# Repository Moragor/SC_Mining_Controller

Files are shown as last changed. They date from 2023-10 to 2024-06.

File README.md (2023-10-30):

# Star Citizen Mining Controller
A handheld mining controller for Star Citizen

Parts:
Arduino Pro Micro: https://www.aliexpress.com/item/32768308647.html

Switches: ON-ON 3-Pin https://www.aliexpress.com/item/4000598302546.html

Power Button: 19mm https://www.aliexpress.com/item/1005003151279874.html?gatewayAdapt=glo2deu

E-Stop: 19mm 3-Pin https://www.aliexpress.com/item/1005003736504591.html?gatewayAdapt=glo2deu

Module Buttons: https://www.aliexpress.com/item/32667944879.html?gatewayAdapt=glo2deu

Slide Potentiometer: ALPS 401547 (RS60112-LIN10K) + ALPS 76561 (KNOPF 4X1,2RT)

Joystick: APEM 3150RAK600

Switch rubber grommets: APEM U598

Front Panel: Order from https://www.schaeffer-ag.de/ (EU) or https://www.frontpanelexpress.com/ (NA)

Demo: https://www.youtube.com/watch?v=b_x-qhPem98

[][cc-by-nc-sa]

[cc-by-nc-sa]: http://creativecommons.org/licenses/by-nc-sa/4.0/
[cc-by-nc-sa-shield]: https://img.shields.io/badge/License-CC%20BY--NC--SA%204.0-lightgrey.svg

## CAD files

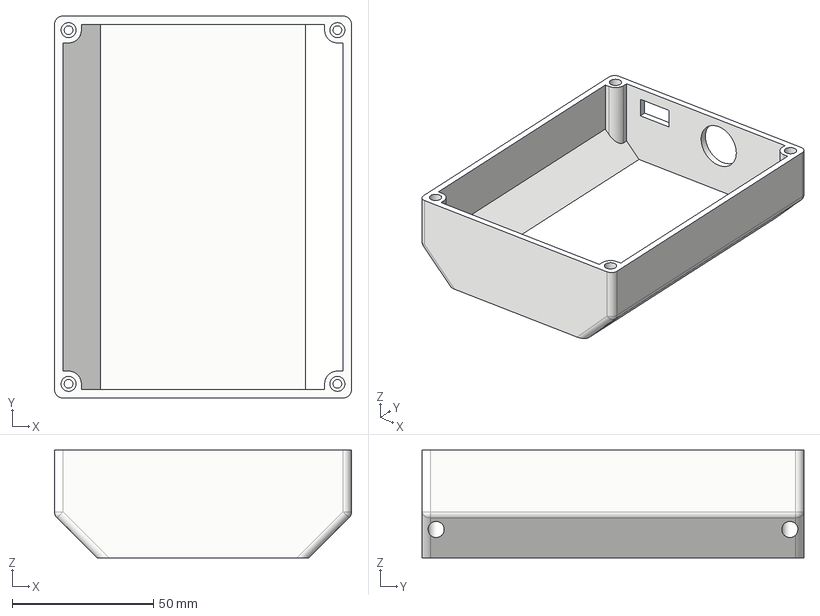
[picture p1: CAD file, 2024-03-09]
3D_Files/Mining Controller Case MKI v16.step
105.0 x 135.0 x 38.0 mm

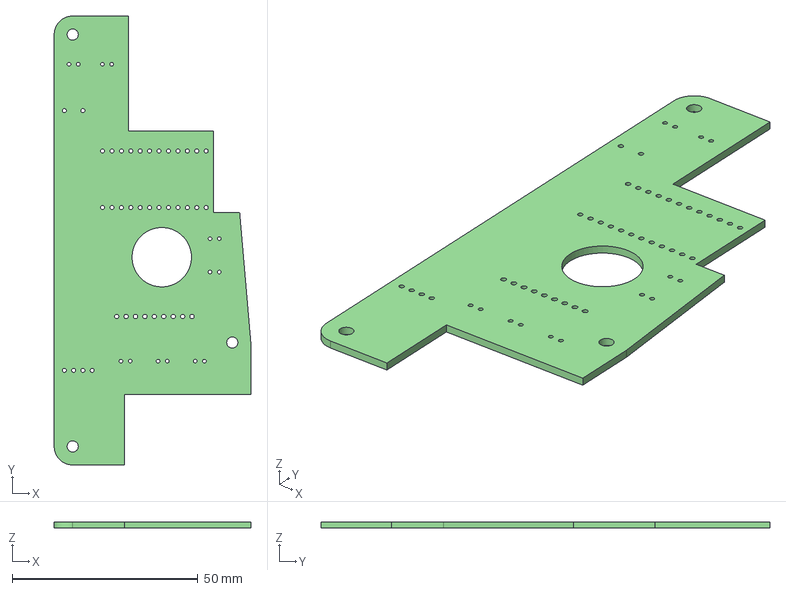
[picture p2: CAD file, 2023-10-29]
KiCad_Files/SC_Mining_Controller_MkI/SC_Mining_Controller_MkI.step
53.0 x 121.0 x 1.60 mm

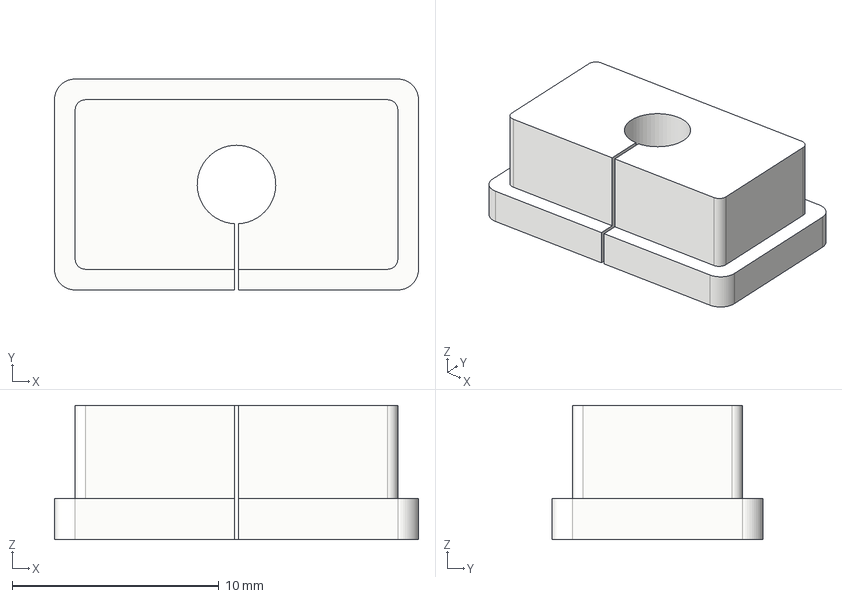
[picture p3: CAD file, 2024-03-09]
3D_Files/Minig Controller Strain Relief v2.step
17.6 x 10.2 x 6.50 mm

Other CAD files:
3D_Files/Case_MKI.stl
3D_Files/Strain_relief.stl

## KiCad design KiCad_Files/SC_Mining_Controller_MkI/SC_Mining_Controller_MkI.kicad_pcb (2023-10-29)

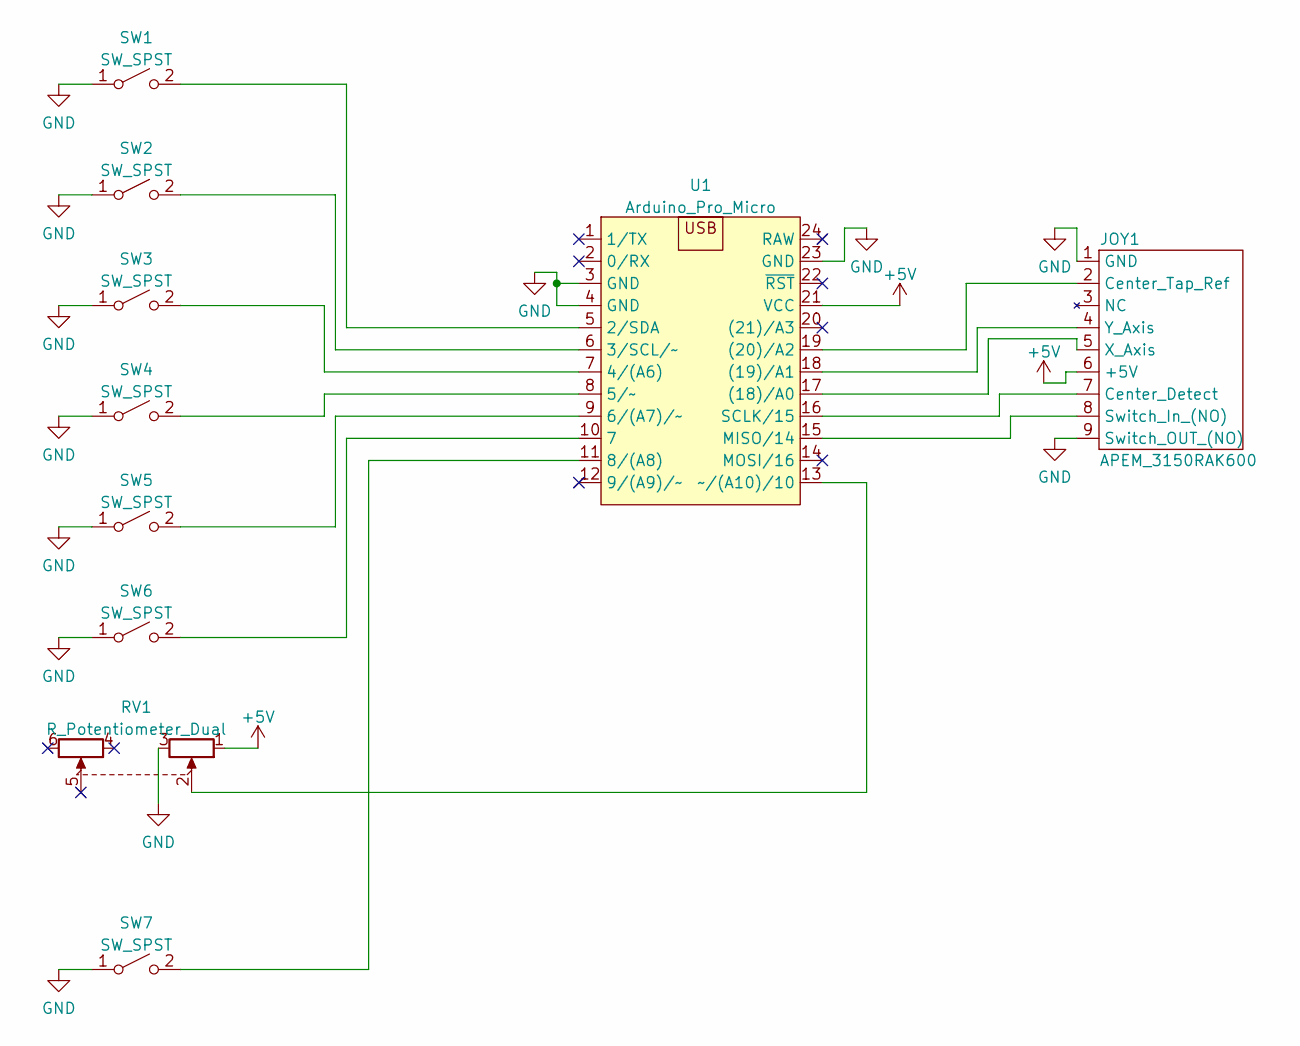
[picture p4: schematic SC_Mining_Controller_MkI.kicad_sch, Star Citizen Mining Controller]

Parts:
JOY1: APEM_3150RAK600; Molex_KK-254_AE-6410-09A_1x09_P2.54mm_Vertical
RV1: R_Potentiometer_Dual; Sliding_Potentiometer_RS60112
SW1, SW2, SW3, SW4, SW5, SW6, SW7: SW_SPST; JST_XH_B2B-XH-A_1x02_P2.50mm_Vertical
U1: Arduino_Pro_Micro; ProMicro

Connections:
+5V: JOY1.6 (+5V), RV1.1, U1.21 (VCC)
GND: JOY1.1 (GND), JOY1.9 (Switch_OUT_(NO)), RV1.3, SW1.1 (A), SW2.1 (A), SW3.1 (A), SW4.1 (A), SW5.1 (A), SW6.1 (A), SW7.1 (A), U1.3 (GND), U1.4 (GND), U1.23 (GND)
unnamed: JOY1.2 (Center_Tap_Ref), U1.19 ((20)/A2)
unnamed: JOY1.4 (Y_Axis), U1.18 ((19)/A1)
unnamed: JOY1.5 (X_Axis), U1.17 ((18)/A0)
unnamed: JOY1.7 (Center_Detect), U1.16 (SCLK/15)
unnamed: JOY1.8 (Switch_In_(NO)), U1.15 (MISO/14)
unnamed: RV1.2, U1.13 (~/(A10)/10)
unnamed: SW1.2 (B), U1.5 (2/SDA)
unnamed: SW2.2 (B), U1.6 (3/SCL/~)
unnamed: SW3.2 (B), U1.7 (4/(A6))
unnamed: SW4.2 (B), U1.8 (5/~)
unnamed: SW5.2 (B), U1.9 (6/(A7)/~)
unnamed: SW6.2 (B), U1.10 (7)
unnamed: SW7.2 (B), U1.11 (8/(A8))

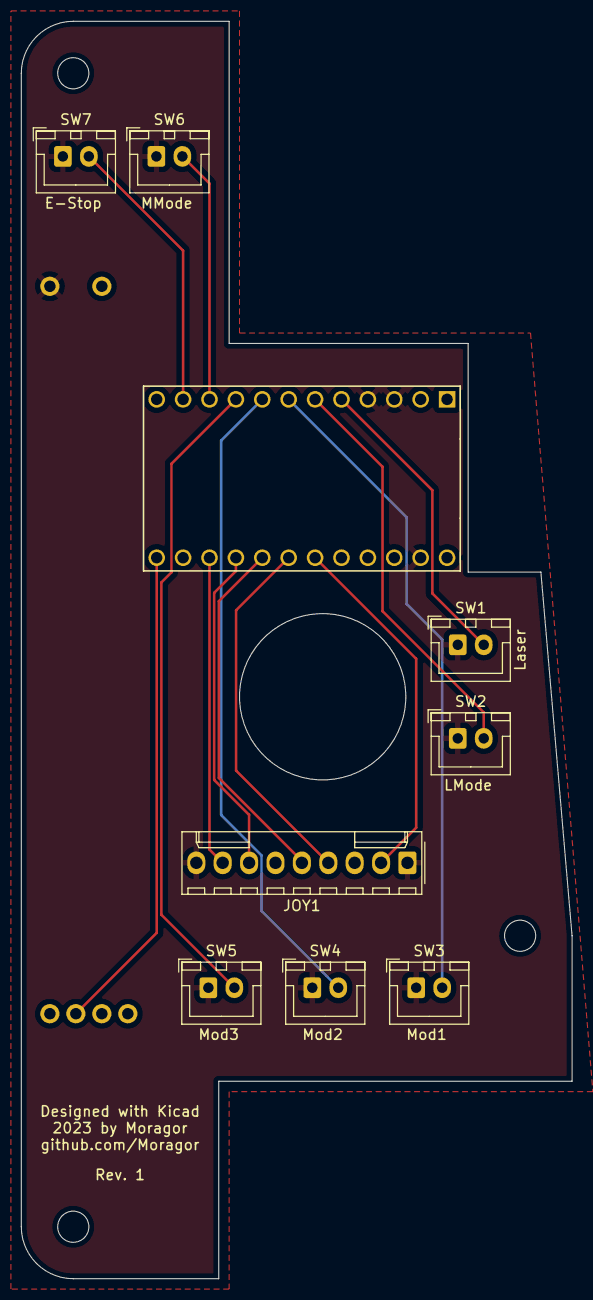
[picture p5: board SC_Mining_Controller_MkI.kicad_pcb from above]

Board: 2 copper layers, 53.0 x 121.0 mm, 10 parts (1 on the bottom side), 15 nets.

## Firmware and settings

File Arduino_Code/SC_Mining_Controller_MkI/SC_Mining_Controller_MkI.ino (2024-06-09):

#include <Bounce2.h>
#include <Joystick.h>     //https://github.com/MHeironimus/ArduinoJoystickLibrary

#define laserPin 2       //0 (array position)
#define lModePin 3       //1
#define mod1Pin 4        //2
#define mod2Pin 5        //3
#define mod3Pin 6        //4
#define mModePin 7       //5
#define eStopPin 8       //6
#define joyButtonPin 14  //7
#define xAxisPin A0
#define yAxisPin A1
#define centerTapPin A2
#define sliderPin A10

byte buttonDelay = 25;
const int numButtons = 8;                                                                                                // Number of buttons
const int buttonPins[numButtons] = { laserPin, lModePin, mod1Pin, mod2Pin, mod3Pin, mModePin, eStopPin, joyButtonPin };  // Pin numbers for your buttons

Bounce debouncer[numButtons];  // Create a debouncer object for each button

//Setting up the features of the joystick
Joystick_ Joystick(JOYSTICK_DEFAULT_REPORT_ID, JOYSTICK_TYPE_JOYSTICK,
                   7, 0,                  // Button Count, Hat Switch Count
                   true, true, true,      // X, Y and Z Axis
                   false, false, false,   // Rx, Ry and Rz Axis
                   false, false,          // Rudder and Throttle
                   false, false, false);  // Accelerator, Brake and Steering

void setup() {
  Joystick.setXAxisRange(0, 1023);  //Output range of the Joystick
  Joystick.setYAxisRange(0, 1023);
  Joystick.setZAxisRange(0, 1023);
  Joystick.begin();

  //Setting up the buttons with the debounce library
  for (int i = 0; i < numButtons; i++) {
    pinMode(buttonPins[i], INPUT_PULLUP);  // Set buttons as INPUT_PULLUP
    debouncer[i].attach(buttonPins[i]);
    debouncer[i].interval(5);  // Debounce interval in milliseconds
  }

  Serial.begin(9600);
}

void loop() {
  //Checking button state changes
  for (int i = 0; i < numButtons; i++) {
    debouncer[i].update();
  }

  //Buttons
  //Laser power
  if (debouncer[0].fell()) {    //.fell meands on button down
    Joystick.pressButton(0);
    delay(buttonDelay);
    Joystick.releaseButton(0);
  }
  //Laser mode
  if (debouncer[1].changed()) { //.changed means any change
    Joystick.pressButton(1);
    delay(buttonDelay);
    Joystick.releaseButton(1);
  }
  //Mod 1
  if (debouncer[2].fell()) {
    Joystick.pressButton(2);
    delay(buttonDelay);
    Joystick.releaseButton(2);
  }
  //Mod 2
  if (debouncer[3].fell()) {
    Joystick.pressButton(3);
    delay(buttonDelay);
    Joystick.releaseButton(3);
  }
  //Mod 3
  if (debouncer[4].fell()) {
    Joystick.pressButton(4);
    delay(buttonDelay);
    Joystick.releaseButton(4);
  }
  //Mining mode
  if (debouncer[5].changed()) {
    Joystick.pressButton(5);
    delay(buttonDelay);
    Joystick.releaseButton(5);
  }
  //E-Stop
  if (debouncer[6].fell()) {
    Joystick.pressButton(5);
    delay(buttonDelay);
    Joystick.releaseButton(5);
  }
  //Joystick button
  if (debouncer[7].fell()) {
    Joystick.pressButton(0);
    delay(buttonDelay);
    Joystick.releaseButton(0);
  }


  //Joystick and Slider output
  int xInput(analogRead(xAxisPin));
  xInput = map(xInput, 0, 1013, 0, 1023);
  Joystick.setXAxis(xInput);
  int yInput(analogRead(yAxisPin));
  yInput = map(yInput, 5, 1017, 0, 1023);
  Joystick.setYAxis(yInput);
  Joystick.setZAxis(analogRead(sliderPin));
}

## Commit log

2023-10-29 Initial Upload
    [SC_Mining_Controller_MkI-B_Cu.gbr, SC_Mining_Controller_MkI-B_Mask.gbr, SC_Mining_Controller_MkI-B_Silkscreen.gbr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]
2024-03-09 Adding pictures and 3D files
    [Case_MKI.stl, Minig Controller Strain Relief v2.step, Mining Controller Case MKI v16.step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]

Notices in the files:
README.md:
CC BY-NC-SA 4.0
